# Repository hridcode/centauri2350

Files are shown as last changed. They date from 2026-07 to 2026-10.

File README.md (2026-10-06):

# Centauri2350

Centauri2350 is a microcontroller board based off the RP2354B chip. It has 44 usable GPIO pins, plus battery charging and an audio DAC.

This is derived from my old board named "Whistle" (which honestly was trash lmao)

## Features

- 150MHz clock speed
- 520KB RAM
- 2MB flash memory
- 48 GPIOs (4 used for onboard LED + I²S connection)
- 8 analog-capable pins
- LiPo battery charging (IP5306)
- Audio DAC (PCM5102A)
- Debug pins
- USB-C connector

## Photos

### Schematic

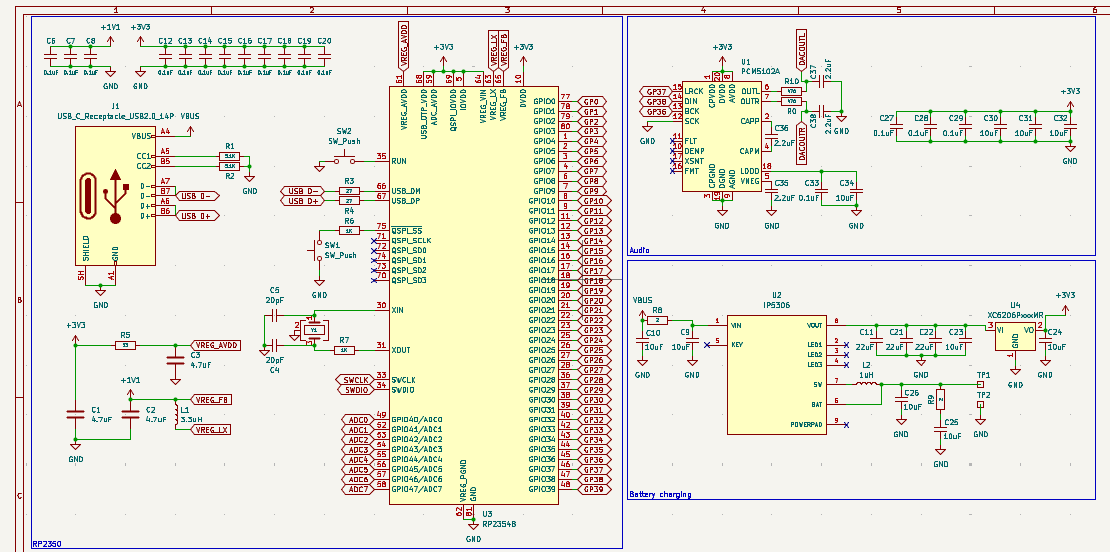
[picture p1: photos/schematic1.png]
PCB schematic, page 1

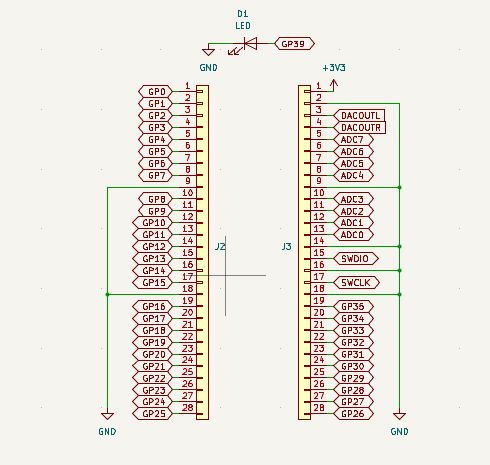
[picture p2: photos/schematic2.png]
PCB schematic, page 2


### PCB

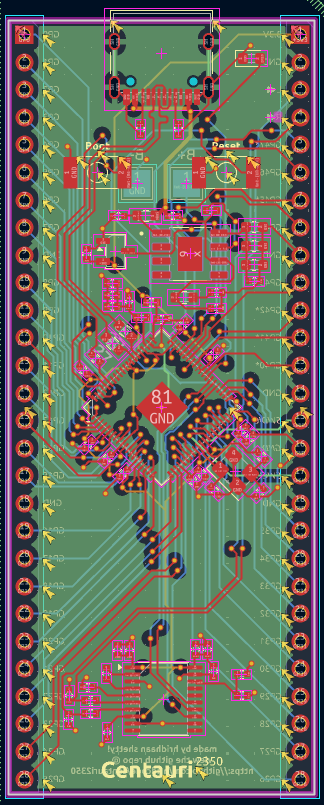
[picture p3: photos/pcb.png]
PCB layout


### 3D model

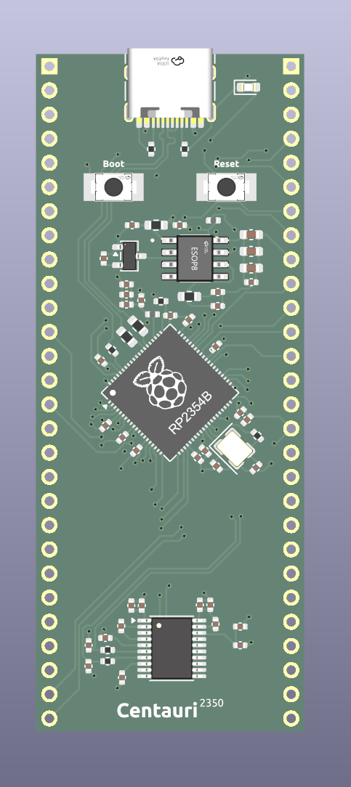
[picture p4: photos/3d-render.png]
3D model of PCB


## BOM

|Part|Quantity|Price|Source|
|---|---|---|---|
|RP2354B|1|$1.620|[LCSC](https://www.lcsc.com/product-detail/C39843328.html)|
|PCM5102A|1|$1.360|[LCSC](https://www.lcsc.com/product-detail/C107671.html)|
|IP5306|1|$0.280|[LCSC](https://www.lcsc.com/product-detail/C181692.html)|
|XC6206P332MR|1|$0.130|[LCSC](https://www.lcsc.com/product-detail/C5446.html)|
|X322512MSB4SI|1|$0.100|[LCSC](https://www.lcsc.com/product-detail/C9002.html)|
|USB-C receptacle|1|$0.100|[LCSC](https://www.lcsc.com/product-detail/C165948.html)|
|3.9x2.9 switch|2|$0.150|[LCSC](https://www.lcsc.com/product-detail/C202388.html)|
|PCB|1|$1.600|[JLCPCB](https://cart.jlcpcb.com/quote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)|
|0402 20pF capacitor|2|$0.027|[LCSC](https://www.lcsc.com/product-detail/C1554.html)|
|0402 0.1uF capacitor|16|$0.088|[LCSC](https://www.lcsc.com/product-detail/C1525.html)|
|0402 2.2uF capacitor|4|$0.026|[LCSC](https://www.lcsc.com/product-detail/C12530.html)|
|0402 4.7uF capacitor|3|$0.063|[LCSC](https://www.lcsc.com/product-detail/C23733.html)|
|0402 10uF capacitor|10|$0.284|[LCSC](https://www.lcsc.com/product-detail/C15525.html)|
|0603 22uF capacitor|3|$0.094|[LCSC](https://www.lcsc.com/product-detail/C59461.html)|
|0402 1uH inductor|1|$0.133|[LCSC](https://www.lcsc.com/product-detail/C84468.html)|
|0402 3.3uH inductor|1|$0.028|[LCSC](https://www.lcsc.com/product-detail/C84474.html)|
|0603 2Ω resistor|2|$0.008|[LCSC](https://www.lcsc.com/product-detail/C22977.html)|
|0603 27Ω resistor|2|$0.008|[LCSC](https://www.lcsc.com/product-detail/C25190.html)|
|0402 33Ω resistor|1|$0.007|[LCSC](https://www.lcsc.com/product-detail/C25105.html)|
|0402 470Ω resistor|2|$0.013|[LCSC](https://www.lcsc.com/product-detail/C25117.html)|
|0402 1KΩ resistor|2|$0.016|[LCSC](https://www.lcsc.com/product-detail/C11702.html)|
|0402 5.1KΩ resistor|2|$0.013|[LCSC](https://www.lcsc.com/product-detail/C25905.html)|
|0603 red LED|1|$0.007|[LCSC](https://www.lcsc.com/product-detail/C2286.html)|
|Total|1|$6.155||

## Notes

Pins marked with an asterisk (*) on the board are ADC pins.
Italicized pin names denote the debug pins.

Have fun making!

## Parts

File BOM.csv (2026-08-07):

Part | Quantity | Price | Link
RP2354B | 1 | 1.620 | https://www.lcsc.com/product-detail/C39843328.html
PCM5102A | 1 | 1.360 | https://www.lcsc.com/product-detail/C107671.html
IP5306 | 1 | 0.280 | https://www.lcsc.com/product-detail/C181692.html
XC6206P332MR | 1 | 0.130 | https://www.lcsc.com/product-detail/C5446.html
X322512MSB4SI | 1 | 0.100 | https://www.lcsc.com/product-detail/C9002.html
USB-C receptacle | 1 | 0.100 | https://www.lcsc.com/product-detail/C165948.html
3.9x2.9 switch | 2 | 0.150 | https://www.lcsc.com/product-detail/C202388.html
PCB | 1 | 0.400 | https://cart.jlcpcb.com/quote?stencilLayer=2&stencilWidth=100&stencilLength=100&stencilCounts=5&plateType=1
0402 20pF capacitor | 2 | 0.027 | https://www.lcsc.com/product-detail/C1554.html
0402 0.1uF capacitor | 16 | 0.088 | https://www.lcsc.com/product-detail/C1525.html
0402 2.2uF capacitor | 4 | 0.026 | https://www.lcsc.com/product-detail/C12530.html
0402 4.7uF capacitor | 3 | 0.063 | https://www.lcsc.com/product-detail/C23733.html
0402 10uF capacitor | 10 | 0.284 | https://www.lcsc.com/product-detail/C15525.html
0603 22uF capacitor | 3 | 0.094 | https://www.lcsc.com/product-detail/C59461.html
0402 1uH inductor | 1 | 0.133 | https://www.lcsc.com/product-detail/C84468.html
0402 3.3uH inductor | 1 | 0.028 | https://www.lcsc.com/product-detail/C84474.html
0603 2Ω resistor | 2 | 0.008 | https://www.lcsc.com/product-detail/C22977.html
0603 27Ω resistor | 2 | 0.008 | https://www.lcsc.com/product-detail/C25190.html
0402 33Ω resistor | 1 | 0.007 | https://www.lcsc.com/product-detail/C25105.html
0402 470Ω resistor | 2 | 0.013 | https://www.lcsc.com/product-detail/C25117.html
0402 1KΩ resistor | 2 | 0.016 | https://www.lcsc.com/product-detail/C11702.html
0402 5.1KΩ resistor | 2 | 0.013 | https://www.lcsc.com/product-detail/C25905.html
0603 red LED | 1 | 0.007 | https://www.lcsc.com/product-detail/C2286.html
Total | 1 | 4.955

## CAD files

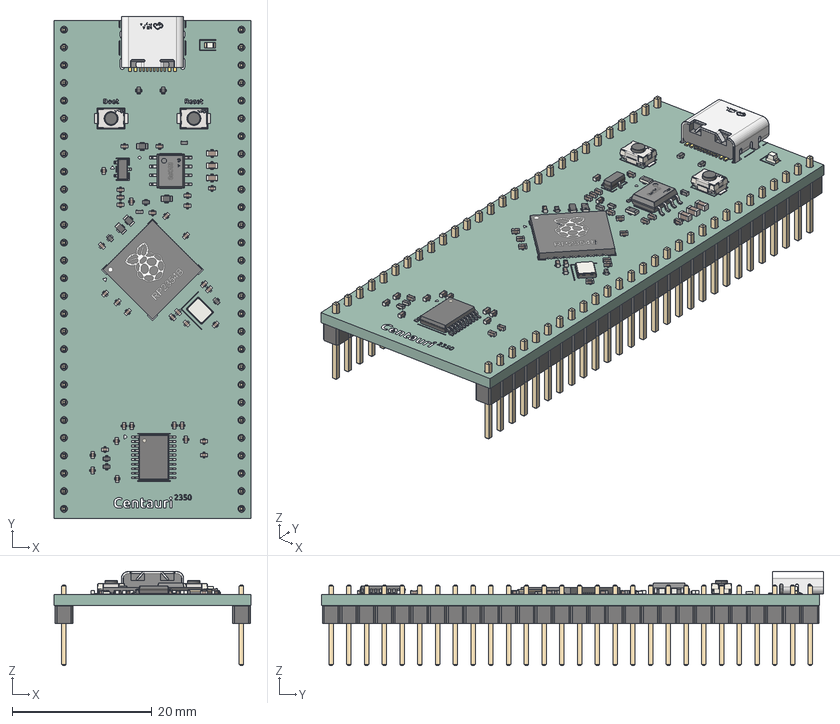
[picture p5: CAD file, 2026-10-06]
production/centauri2350.step
28.2 x 71.8 x 13.5 mm
L_0402_1005Metric x 2
C_0402_1005Metric x 35
R_0402_1005Metric x 7
SW-SMD_L3.9-W2.9-H2.0-LS4.8 x 2
Crystal_SMD_3225-4Pin_3.2x2.5mm
ESOP-8_L4.9-W3.9-H1.6-LS6.0-P1.27
RP2354B
C_0603_1608Metric x 3
USB-C_SMD-TYPE-C-31-M-12_1
R_0603_1608Metric x 4
LED_0603_1608Metric
TSSOP-20_4.4x6.5mm_P0.65mm
SOT-23-3
PinHeader_1x28_P2.54mm_Vertical x 2
centauri_silkscreen x 2
centauri_PCB

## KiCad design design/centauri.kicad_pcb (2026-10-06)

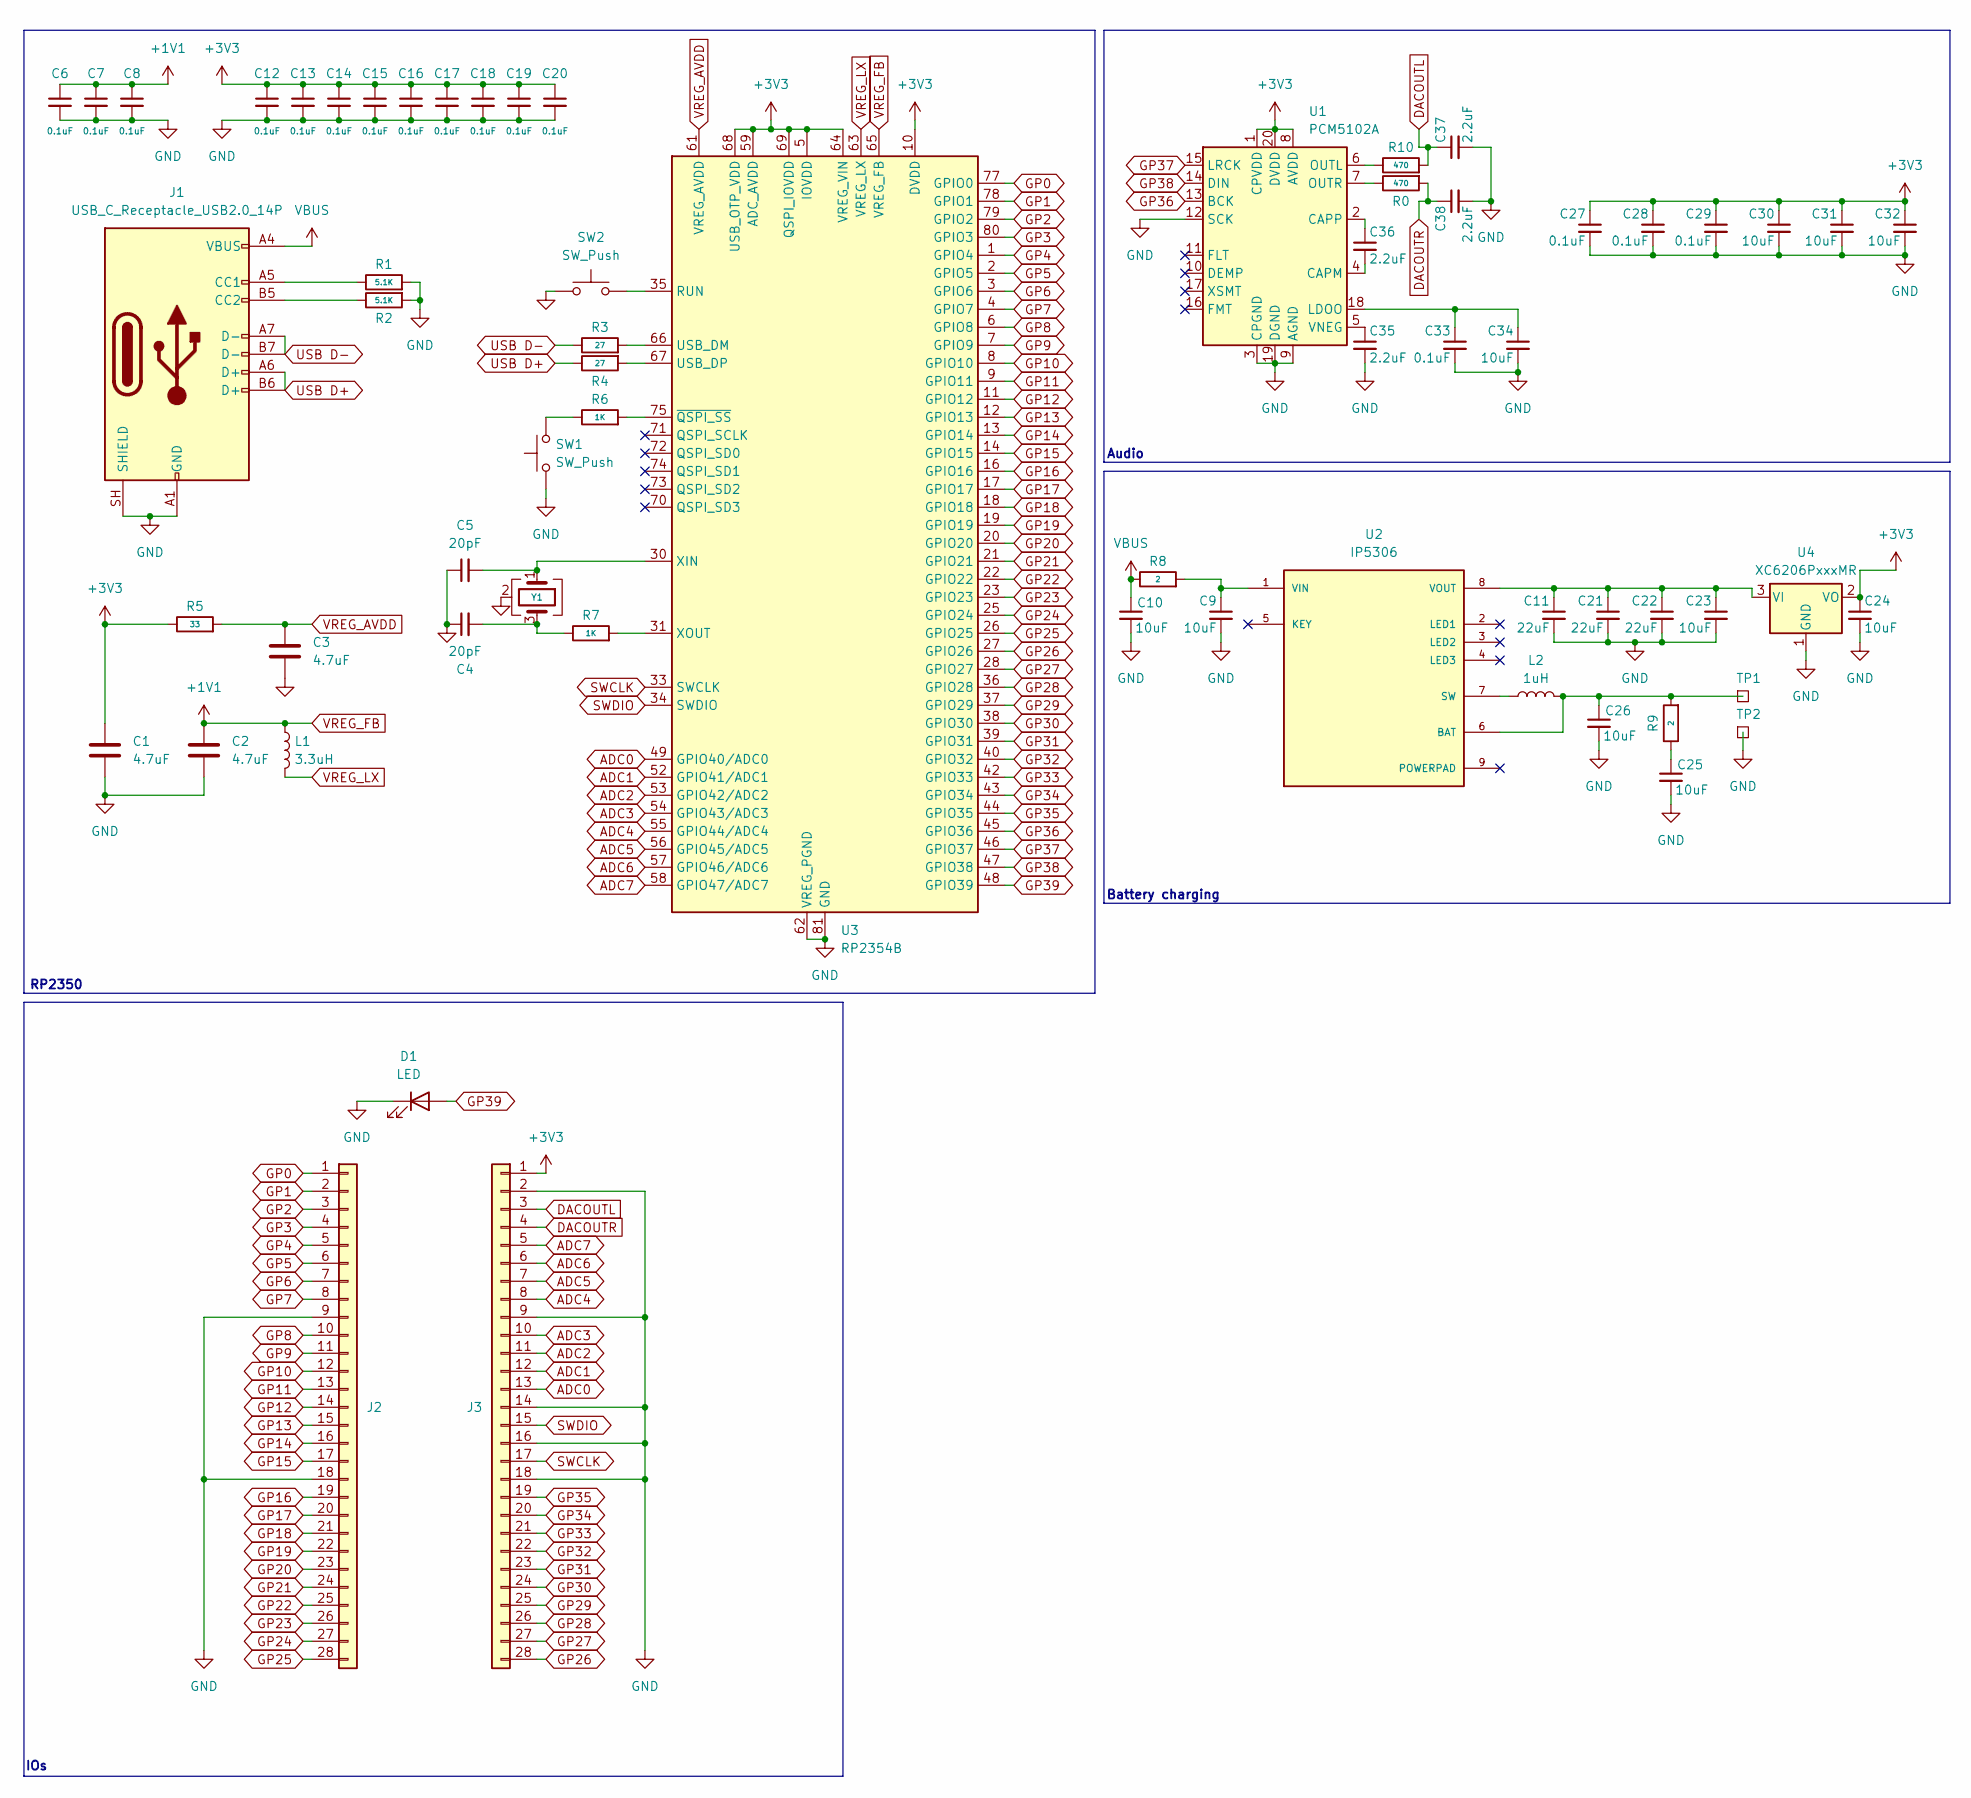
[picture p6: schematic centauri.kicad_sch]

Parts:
C1, C2, C3: 4.7uF; C_0402_1005Metric; MPN C23733
C4, C5: 20pF; C_0402_1005Metric; MPN C1554
C6, C7, C8, C12, C13, C14, C15, C16, C17, C18, C19, C20, C27, C28, C29, C33: 0.1uF; C_0402_1005Metric; MPN C1525
C9, C10, C23, C24, C25, C26, C30, C31, C32, C34: 10uF; C_0402_1005Metric; MPN C15525
C11, C21, C22: 22uF; C_0603_1608Metric; MPN C59461
C35, C36, C37, C38: 2.2uF; C_0402_1005Metric; MPN C12530
D1: LED; LED_0603_1608Metric; MPN C2286
J1: USB_C_Receptacle_USB2.0_14P; USB_C_Receptacle_HRO_TYPE-C-31-M-12; MPN C165948
J2, J3: Conn_01x28; PinHeader_1x28_P2.54mm_Vertical
L1: 3.3uH; L_0402_1005Metric; MPN C84474
L2: 1uH; L_0402_1005Metric; MPN C84468
R0, R10: 470; R_0402_1005Metric; MPN C25117
R1, R2: 5.1K; R_0402_1005Metric; MPN C25905
R3, R4: 27; R_0603_1608Metric; MPN C25190
R5: 33; R_0402_1005Metric; MPN C25105
R6, R7: 1K; R_0402_1005Metric; MPN C11702
R8, R9: 2; R_0603_1608Metric; MPN C22977
SW1, SW2: SW_Push; button_342
TP1, TP2: TestPoint_Square; TestPoint_Pad_2.5x2.5mm
U1: PCM5102A; TSSOP-20_4.4x6.5mm_P0.65mm; MPN C107671
U2: IP5306; eSOP-8; PARTREV 1.31
U3: RP2354B; QFN-80-1EP_10x10mm_P0.4mm_EP3.4x3.4mm; MPN C39843328
U4: XC6206PxxxMR; SOT-23-3; MPN C5446
Y1: Crystal_GND24; Crystal_SMD_3225-4Pin_3.2x2.5mm; MPN C9002

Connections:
+3V3: C1.1, C12.1, C13.1, C14.1, C15.1, C16.1, C17.1, C18.1, C19.1, C20.1, C24.1, C27.1, C28.1, C29.1, C30.1, C31.1, C32.1, J3.1, R5.1, U1.1 (CPVDD), U1.8 (AVDD), U1.20 (DVDD), U3.5 (IOVDD), U3.10 (DVDD), U3.15 (IOVDD), U3.24 (IOVDD), U3.29 (IOVDD), U3.32 (DVDD), U3.41 (IOVDD), U3.50 (IOVDD), U3.51 (DVDD), U3.59 (ADC_AVDD), U3.60 (IOVDD), U3.64 (VREG_VIN), U3.68 (USB_OTP_VDD), U3.69 (QSPI_IOVDD), U3.76 (IOVDD), U4.2 (VO)
ADC0: J3.13, U3.49 (GPIO40/ADC0)
ADC1: J3.12, U3.52 (GPIO41/ADC1)
ADC2: J3.11, U3.53 (GPIO42/ADC2)
ADC3: J3.10, U3.54 (GPIO43/ADC3)
ADC4: J3.8, U3.55 (GPIO44/ADC4)
ADC5: J3.7, U3.56 (GPIO45/ADC5)
ADC6: J3.6, U3.57 (GPIO46/ADC6)
ADC7: J3.5, U3.58 (GPIO47/ADC7)
DACOUTL: C37.1, J3.3, R10.2
DACOUTR: C38.1, J3.4, R0.2
GND: C1.2, C2.2, C3.2, C4.1, C5.1, C6.2, C7.2, C8.2, C9.2, C10.2, C11.2, C12.2, C13.2, C14.2, C15.2, C16.2, C17.2, C18.2, C19.2, C20.2, C21.2, C22.2, C23.2, C24.2, C25.2, C26.2, C27.2, C28.2, C29.2, C30.2, C31.2, C32.2, C33.2, C34.2, C35.2, C37.2, C38.2, D1.1 (K), J1.A1 (GND), J1.A12 (GND), J1.B1 (GND), J1.B12 (GND), J1.SH (SHIELD), J2.9, J2.18, J3.2, J3.9, J3.14, J3.16, J3.18, R1.2, R2.2, SW1.1, SW2.1, TP2.1 (1_1), U1.3 (CPGND), U1.9 (AGND), U1.12 (SCK), U1.19 (DGND), U3.62 (VREG_PGND), U3.81 (GND), U4.1 (GND), Y1.2 (G), Y1.4 (G)
GP0: J2.1, U3.77 (GPIO0)
GP1: J2.2, U3.78 (GPIO1)
GP2: J2.3, U3.79 (GPIO2)
GP3: J2.4, U3.80 (GPIO3)
GP4: J2.5, U3.1 (GPIO4)
GP5: J2.6, U3.2 (GPIO5)
GP6: J2.7, U3.3 (GPIO6)
GP7: J2.8, U3.4 (GPIO7)
GP8: J2.10, U3.6 (GPIO8)
GP9: J2.11, U3.7 (GPIO9)
GP10: J2.12, U3.8 (GPIO10)
GP11: J2.13, U3.9 (GPIO11)
GP12: J2.14, U3.11 (GPIO12)
GP13: J2.15, U3.12 (GPIO13)
GP14: J2.16, U3.13 (GPIO14)
GP15: J2.17, U3.14 (GPIO15)
GP16: J2.19, U3.16 (GPIO16)
GP17: J2.20, U3.17 (GPIO17)
GP18: J2.21, U3.18 (GPIO18)
GP19: J2.22, U3.19 (GPIO19)
GP20: J2.23, U3.20 (GPIO20)
GP21: J2.24, U3.21 (GPIO21)
GP22: J2.25, U3.22 (GPIO22)
GP23: J2.26, U3.23 (GPIO23)
GP24: J2.27, U3.25 (GPIO24)
GP25: J2.28, U3.26 (GPIO25)
GP26: J3.28, U3.27 (GPIO26)
GP27: J3.27, U3.28 (GPIO27)
GP28: J3.26, U3.36 (GPIO28)
GP29: J3.25, U3.37 (GPIO29)
GP30: J3.24, U3.38 (GPIO30)
GP31: J3.23, U3.39 (GPIO31)
GP32: J3.22, U3.40 (GPIO32)
GP33: J3.21, U3.42 (GPIO33)
GP34: J3.20, U3.43 (GPIO34)
GP35: J3.19, U3.44 (GPIO35)
GP36: U1.13 (BCK), U3.45 (GPIO36)
GP37: U1.15 (LRCK), U3.46 (GPIO37)
GP38: U1.14 (DIN), U3.47 (GPIO38)
GP39: D1.2 (A), U3.48 (GPIO39)
unnamed: C4.2, R7.1, Y1.3
unnamed: C25.1, R9.1
unnamed: J1.A5 (CC1), R1.1
unnamed: J1.B5 (CC2), R2.1
unnamed: R6.1, SW1.2
unnamed: C36.2, U1.4 (CAPM)
unnamed: C36.1, U1.2 (CAPP)
unnamed: C33.1, C34.1, U1.18 (LDOO)
unnamed: R10.1, U1.6 (OUTL)
unnamed: R0.1, U1.7 (OUTR)
unnamed: C35.1, U1.5 (VNEG)
unnamed: C26.1, L2.2, R9.2, TP1.1 (1_1), U2.6 (BAT)
unnamed: L2.1, U2.7 (SW)
unnamed: C9.1, R8.2, U2.1 (VIN)
unnamed: C11.1, C21.1, C22.1, C23.1, U2.8 (VOUT), U4.3 (VI)
unnamed: SW2.2, U3.35 (RUN)
unnamed: R3.2, U3.66 (USB_DM)
unnamed: R4.2, U3.67 (USB_DP)
unnamed: C5.2, U3.30 (XIN), Y1.1
unnamed: R7.2, U3.31 (XOUT)
unnamed: R6.2, U3.75 (~QSPI_SS)
SWCLK: J3.17, U3.33 (SWCLK)
SWDIO: J3.15, U3.34 (SWDIO)
USB D+: J1.A6 (D+), J1.B6 (D+), R4.1
USB D-: J1.A7 (D-), J1.B7 (D-), R3.1
VBUS: C10.1, J1.A4 (VBUS), J1.A9 (VBUS), J1.B4 (VBUS), J1.B9 (VBUS), R8.1
VREG_AVDD: C3.1, R5.2, U3.61 (VREG_AVDD)
VREG_FB: C2.1, C6.1, C7.1, C8.1, L1.1, U3.65 (VREG_FB)
VREG_LX: L1.2, U3.63 (VREG_LX)

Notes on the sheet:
Audio
Battery charging
RP2350
IOs

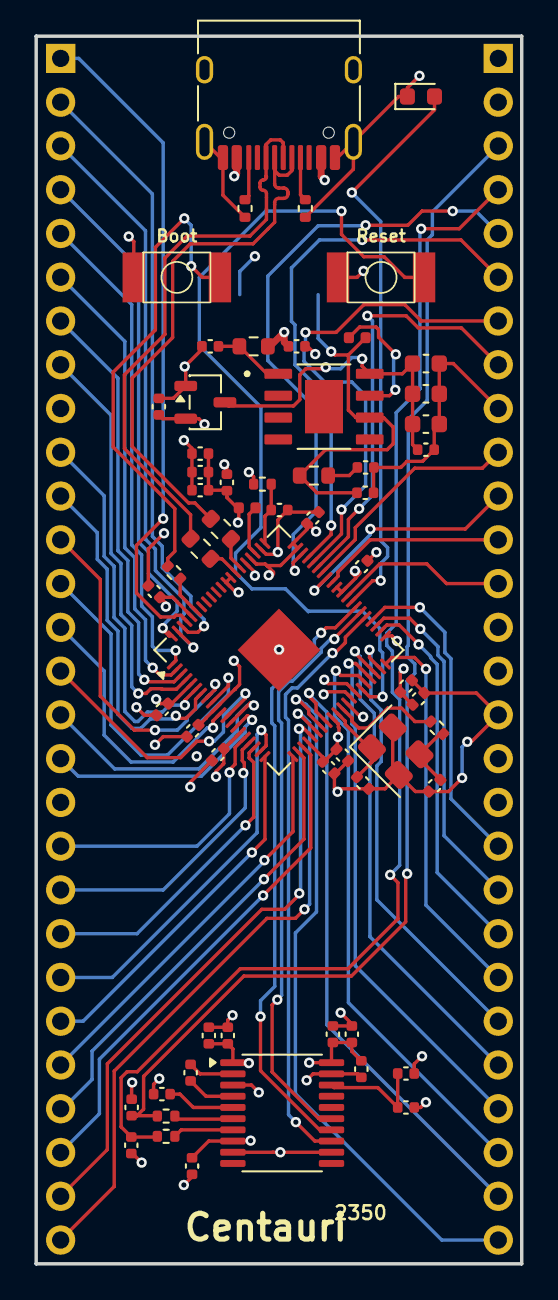
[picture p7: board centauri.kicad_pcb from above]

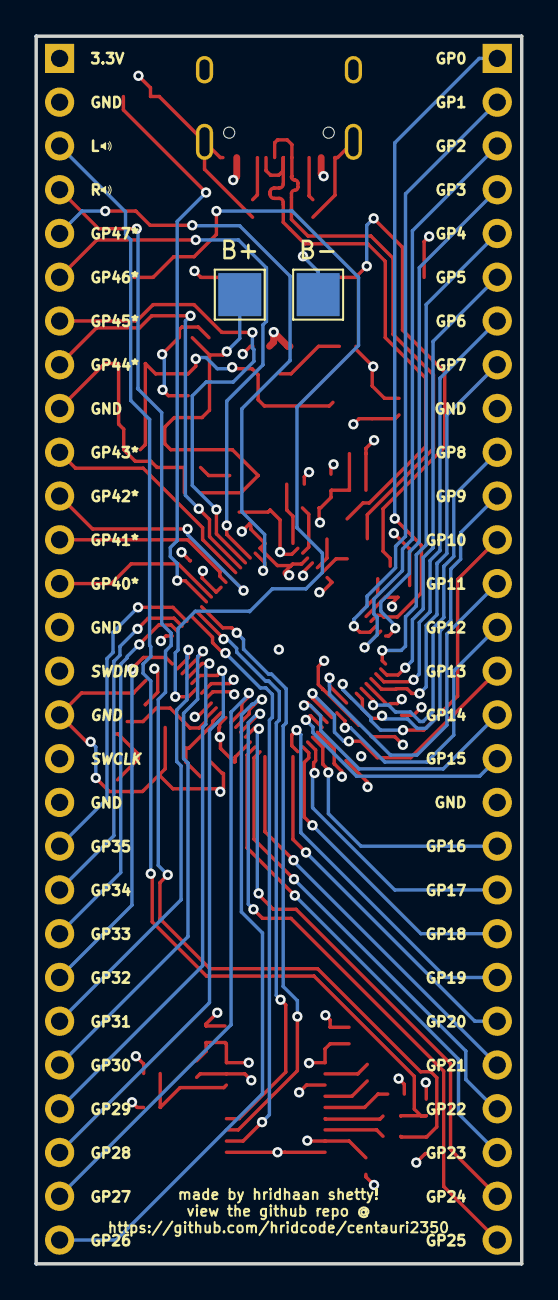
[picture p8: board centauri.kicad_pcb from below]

Board: 4 copper layers, 28.2 x 71.2 mm, 64 parts (4 on the bottom side), 81 nets.

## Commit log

2026-07-31 Added photos, production files, BOM.csv, and README.md
    [BOM.csv, bom.csv, positions.csv]
2026-07-31 Added web folder
    [positions.csv]
2026-07-31 Added 3D model
    [centauri2350.step]
2026-07-31 Added design files
    [centauri.kicad_pcb, centauri.kicad_sch]
2026-08-02 Added table BOM in README.md
2026-08-07 Added passive components to BOM.csv and README.m
    [BOM.csv]
2026-09-30 Fixed PCB and Gerber files
    [centauri.kicad_pcb]
2026-10-06 Fixed PCB and README.md images
    [centauri.kicad_pcb, centauri2350.step, positions.csv]
